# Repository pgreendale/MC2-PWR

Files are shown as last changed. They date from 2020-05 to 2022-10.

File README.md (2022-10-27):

# MC2-PWR compact Eurorack Power Supply
85TE Modular Case - Powersupply

# Introduction 
This Project is a quick - and Dirty Powersupply, which I designed for my modular Eurorack Case. It is relatvely cheap to bild (<60€ for parts). 
To keep tings simple, it has a singlelayer design, which can be easily etched at home (i prefer photolithographic etching, big planes could be difficult to be done with toner transfer). 

# Features 
* +- 12V dual Power supply based on Linear regulators 
* common Gate/CV rail can be divided to use two groups with common Gate/CV
* two 1.5A Fuses to protect against overcurrent 
* screwhole with GND connection for shielding backplates if necessary 

# Parts 
* parts are ordered from Reichelt, a BOM is included in files. 

# Disclaimer 
This project was designed for experienced build. Especially the installation the transformer requires educated building of line powered electronics. To keep things safe, I recommend extra fusing the transformer against overheating and overcurrent on the primary side. Building and operating is done on your own risk! 

Please check the supply under load (take i.E. 10W 12V Lightbulbs from cars etc. one from gnd to +12V and one from gnd to -12V)  first before connecting any Eurorack modules to it. 

# Else 
License GPL v.3
If you like the design or feel the need to make it better, feel free to contact me.

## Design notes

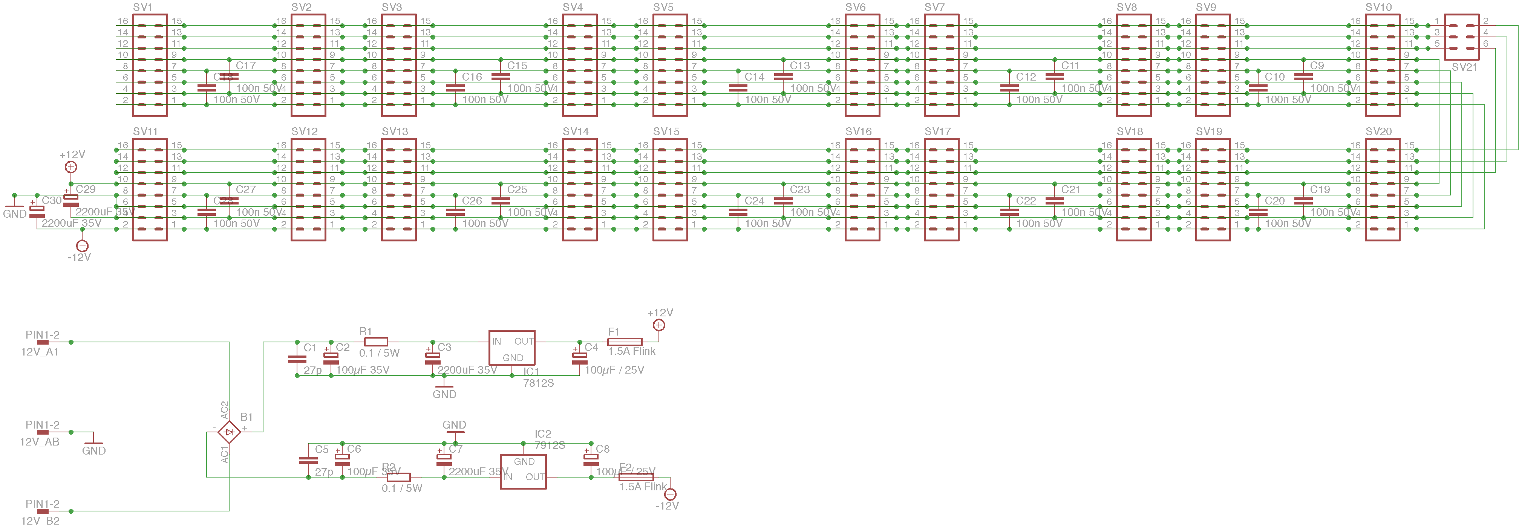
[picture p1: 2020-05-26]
Schematics/Powersupply V 1.10 Schaltplan.png

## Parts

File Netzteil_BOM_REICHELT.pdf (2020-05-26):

## - Netzteil BOM (Reichelt) :

Part | Link | Partnumber (Reichelt) | Rastermaß (mm)
C13 Kaltgeräte male, Einbau | | KES 1 S
Sicherungshalter 5x20 Fronteinbau | | PL126001 | 5x20
Ringkerntrafo 50VA 2x12V, > 1.5A | | RKT 5012
Befestigungsmaterial Ringkern | | mitgeliefert
Flachstecker | | RND 465-00013 | 2,8x0,8
Flachsteckhülse | | RND 465-00056 | 2,8 x 0,8 mm
Graetzbrücke | | KBP 294G TSC
Keramik, 27p | | Kerko 27p | 5
100µF, 35V | | RAD FR 100/35 | 2,5mm
2200µF, 25V | | RAD 2.200/35 | 7,5 mm
0.1Ohm, 0.5W | | ARC ACS5S R 10 K | 13mm = 15mm RM
100uF 25V Low ESR | | FM-A 100U 25 | 2,5 mm
2200uF 25V | | RAD 2.200/35 | 7,5 mm
100nF | | Z5U-2,5 100N | 2,5mm
2k2 Widerstand 0207 | | Metall 2,20K | 7,5mm / 2,5mm
Wannenstecker Male, 8x2, 2.5mm | | WSL 16G | 2,54mm
Crimpstecker, Female, 8x2, 2.5mm | | PFL 16 | 2,54mm
Flachband 16Pol | | AWG 28-16G 3M
Kühlkörper < 3.7*C/W | | V PR127/94-M3
Kühlkörperclip 2,5mm | | MC 725 | 9,1mm
Sicherungshalter 5x20mm print | | PL 112000 | 22,5mm
Sicherungen 1.5A Flink | | FLINK 1.6A

•

# Netzteil

Sonntag, 25. November 2018 19:02

Amount | Cost / Piece (incl. MwSt) € | Cost sum €
1 | 0,86 | 0,86
1 | 0,45 | 0,45
1 | 16,80 | 16,80
6 | 4,59 (á 100) | 4,59
6 | 3,90 (á 100) | 3,90
1 | 0,31 | 0,31
2 | 0,05 | 0,10
2 | 0,23 | 0,46
2 | 0,28 | 0,56
2 | 0,48 | 0,96
2 | 0,14 | 0,28
2 | 0,28 | 0,56
20 | 0,04 | 0,80
2 | 0,082 | 0,164
20 | 0,130 | 2,60
40 | 0,175 | 7,00
10 [m] | 2,10 | 6,30
1 | 2,30 | 2,30
2 | 0,29 | 0,58
2 | 0,190 | 0,38
2 | 0,30 | 0,60

Platinenmaterial | FPE 160x100 | 160x100mm
Befestigungsmaterial

1 | 2,70 | 2,70
| ??
| SUMME | 53,254

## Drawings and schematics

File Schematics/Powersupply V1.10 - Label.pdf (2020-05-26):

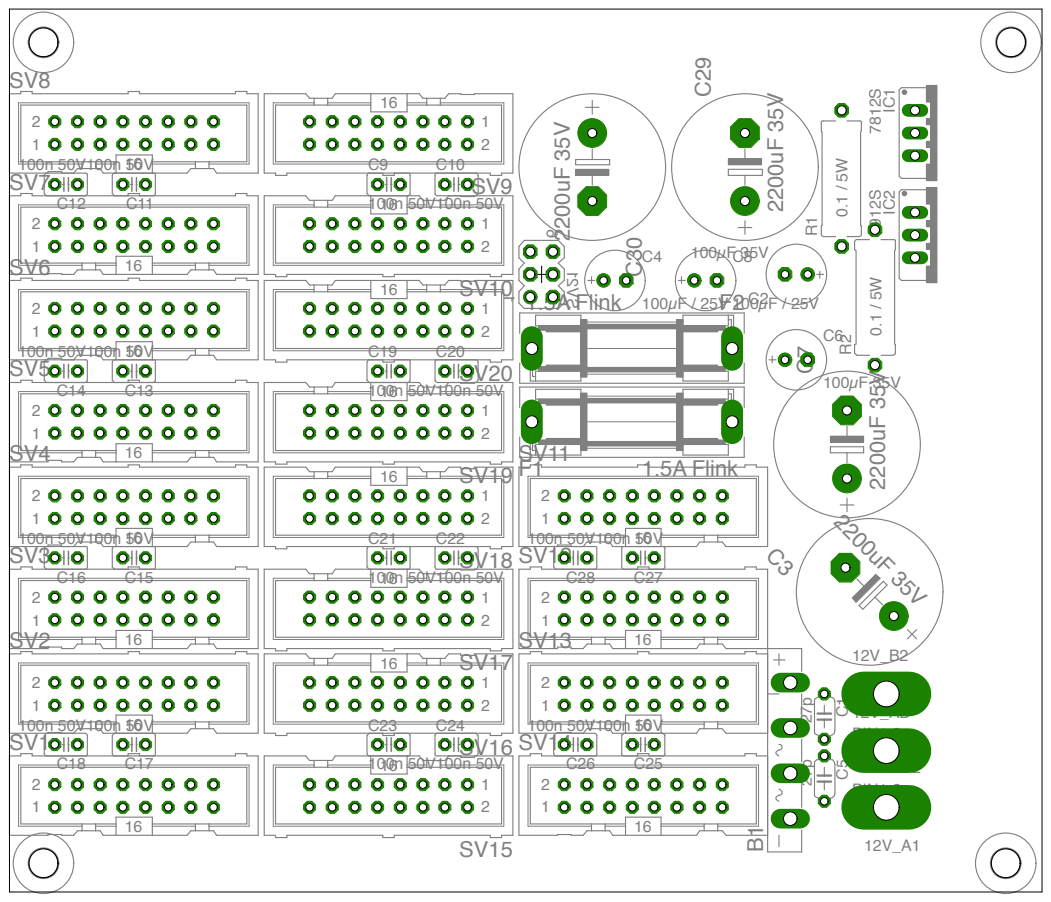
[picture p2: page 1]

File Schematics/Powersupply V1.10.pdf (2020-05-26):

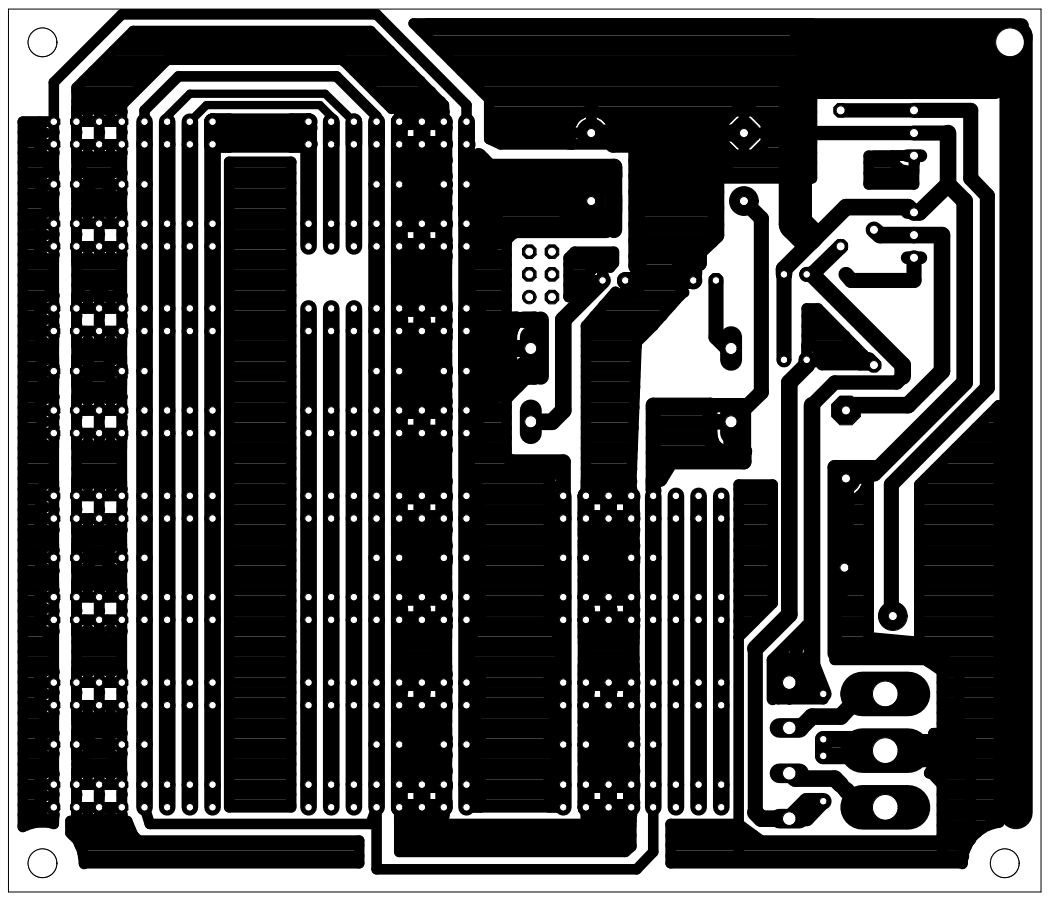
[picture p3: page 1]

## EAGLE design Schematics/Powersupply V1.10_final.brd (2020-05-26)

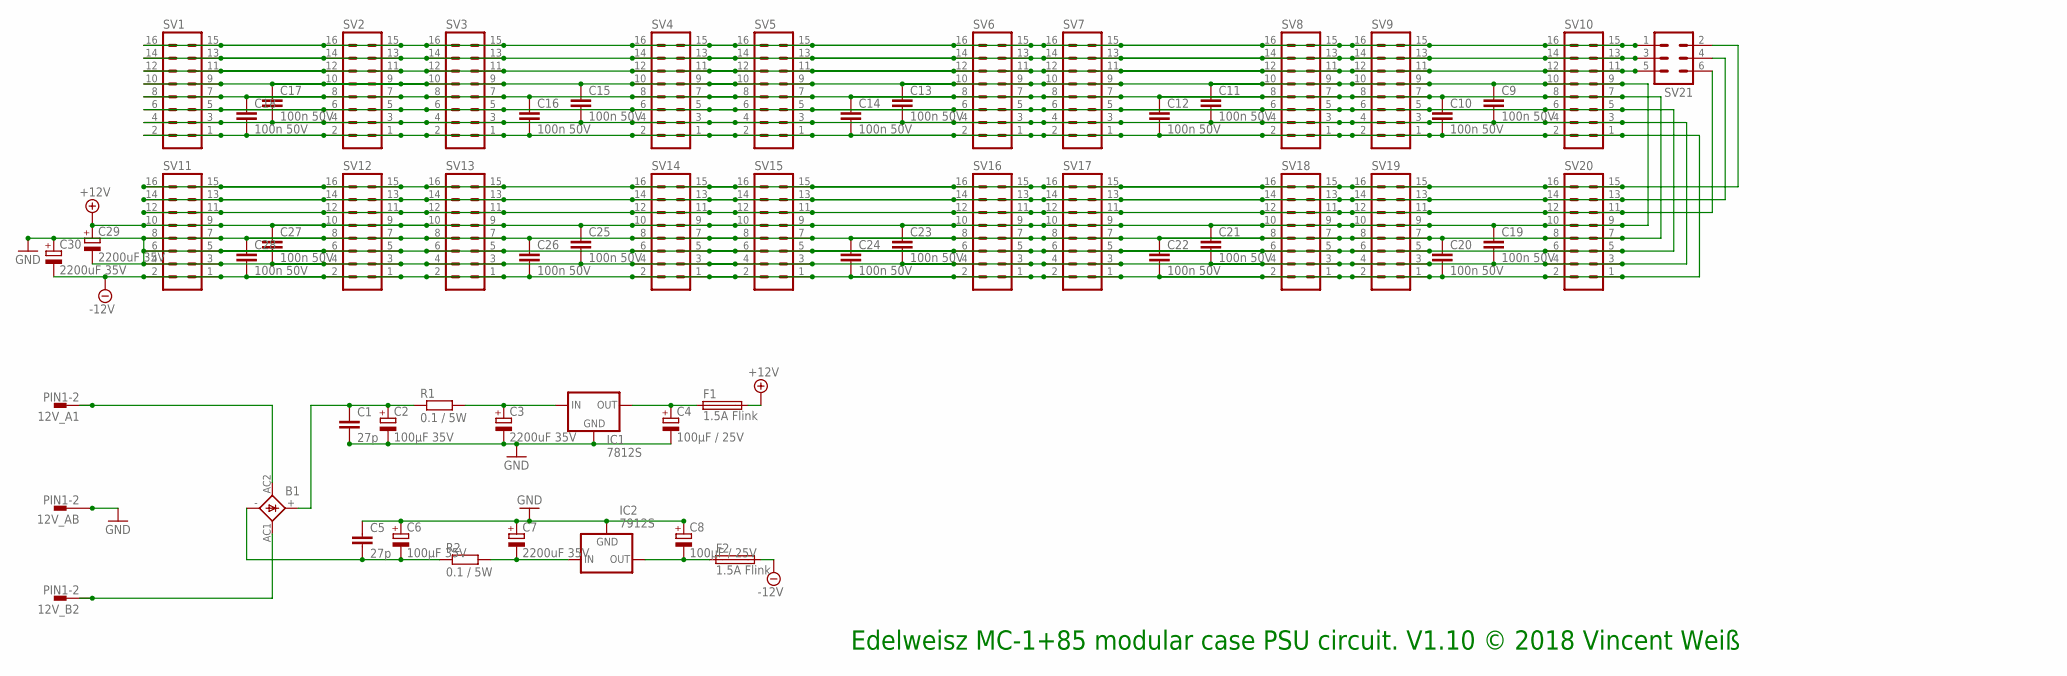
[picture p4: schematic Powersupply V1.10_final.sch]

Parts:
12V_A1, 12V_AB, 12V_B2: PIN1-2; 62221
B1: GBU4; GBU4S
C1, C5: 27p; C050-024X044
C2, C6: 100µF 35V; E2,5-7
C3, C7, C29, C30: 2200uF 35V; E7,5-16
C4, C8: 100µF / 25V; E2,5-7
C9, C10, C11, C12, C13, C14, C15, C16, C17, C18, C19, C20, C21, C22, C23, C24, C25, C26, C27, C28: 100n 50V; C025-025X050
F1, F2: 1.5A Flink; SH22,5
IC1: 7812S; 78XXS
IC2: 7912S; 79XXS
R1, R2: 0.1 / 5W; P0613/15
SV1, SV2, SV3, SV4, SV5, SV6, SV7, SV8, SV9, SV10, SV11, SV12, SV13, SV14, SV15, SV16, SV17, SV18, SV19, SV20: ML16
SV21: MA03-2

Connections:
+12V: C9.1, C11.1, C13.1, C15.1, C17.1, C19.1, C21.1, C23.1, C25.1, C27.1, C29.+, F1.2, SV1.9, SV1.10, SV2.9, SV2.10, SV3.9, SV3.10, SV4.9, SV4.10, SV5.9, SV5.10, SV6.9, SV6.10, SV7.9, SV7.10, SV8.9, SV8.10, SV9.9, SV9.10, SV10.9, SV10.10, SV11.9, SV11.10, SV12.9, SV12.10, SV13.9, SV13.10, SV14.9, SV14.10, SV15.9, SV15.10, SV16.9, SV16.10, SV17.9, SV17.10, SV18.9, SV18.10, SV19.9, SV19.10, SV20.9, SV20.10
-12V: C10.2, C12.2, C14.2, C16.2, C18.2, C20.2, C22.2, C24.2, C26.2, C28.2, C30.-, F2.2, SV1.1, SV1.2, SV2.1, SV2.2, SV3.1, SV3.2, SV4.1, SV4.2, SV5.1, SV5.2, SV6.1, SV6.2, SV7.1, SV7.2, SV8.1, SV8.2, SV9.1, SV9.2, SV10.1, SV10.2, SV11.1, SV11.2, SV12.1, SV12.2, SV13.1, SV13.2, SV14.1, SV14.2, SV15.1, SV15.2, SV16.1, SV16.2, SV17.1, SV17.2, SV18.1, SV18.2, SV19.1, SV19.2, SV20.1, SV20.2
GND: 12V_AB.1, C1.2, C2.-, C3.-, C4.-, C5.1, C6.+, C7.+, C8.+, C9.2, C10.1, C11.2, C12.1, C13.2, C14.1, C15.2, C16.1, C17.2, C18.1, C19.2, C20.1, C21.2, C22.1, C23.2, C24.1, C25.2, C26.1, C27.2, C28.1, C29.-, C30.+, IC1.GND, IC2.GND, SV1.3, SV1.4, SV1.5, SV1.6, SV1.7, SV1.8, SV2.3, SV2.4, SV2.5, SV2.6, SV2.7, SV2.8, SV3.3, SV3.4, SV3.5, SV3.6, SV3.7, SV3.8, SV4.3, SV4.4, SV4.5, SV4.6, SV4.7, SV4.8, SV5.3, SV5.4, SV5.5, SV5.6, SV5.7, SV5.8, SV6.3, SV6.4, SV6.5, SV6.6, SV6.7, SV6.8, SV7.3, SV7.4, SV7.5, SV7.6, SV7.7, SV7.8, SV8.3, SV8.4, SV8.5, SV8.6, SV8.7, SV8.8, SV9.3, SV9.4, SV9.5, SV9.6, SV9.7, SV9.8, SV10.3, SV10.4, SV10.5, SV10.6, SV10.7, SV10.8, SV11.3, SV11.4, SV11.5, SV11.6, SV11.7, SV11.8, SV12.3, SV12.4, SV12.5, SV12.6, SV12.7, SV12.8, SV13.3, SV13.4, SV13.5, SV13.6, SV13.7, SV13.8, SV14.3, SV14.4, SV14.5, SV14.6, SV14.7, SV14.8, SV15.3, SV15.4, SV15.5, SV15.6, SV15.7, SV15.8, SV16.3, SV16.4, SV16.5, SV16.6, SV16.7, SV16.8, SV17.3, SV17.4, SV17.5, SV17.6, SV17.7, SV17.8, SV18.3, SV18.4, SV18.5, SV18.6, SV18.7, SV18.8, SV19.3, SV19.4, SV19.5, SV19.6, SV19.7, SV19.8, SV20.3, SV20.4, SV20.5, SV20.6, SV20.7, SV20.8
unnamed: B1.-, C5.2, C6.-, R2.1
unnamed: 12V_A1.1, B1.AC2 (AC1)
unnamed: 12V_B2.1, B1.AC1 (AC2)
unnamed: B1.+, C1.1, C2.+, R1.1
unnamed: C3.+, IC1.IN, R1.2
unnamed: C7.-, IC2.IN, R2.2
unnamed: C4.+, F1.1, IC1.OUT
unnamed: C8.-, F2.1, IC2.OUT
unnamed: SV1.15, SV1.16, SV2.15, SV2.16, SV3.15, SV3.16, SV4.15, SV4.16, SV5.15, SV5.16, SV6.15, SV6.16, SV7.15, SV7.16, SV8.15, SV8.16, SV9.15, SV9.16, SV10.15, SV10.16, SV21.1
unnamed: SV1.13, SV1.14, SV2.13, SV2.14, SV3.13, SV3.14, SV4.13, SV4.14, SV5.13, SV5.14, SV6.13, SV6.14, SV7.13, SV7.14, SV8.13, SV8.14, SV9.13, SV9.14, SV10.13, SV10.14, SV21.3
unnamed: SV1.11, SV1.12, SV2.11, SV2.12, SV3.11, SV3.12, SV4.11, SV4.12, SV5.11, SV5.12, SV6.11, SV6.12, SV7.11, SV7.12, SV8.11, SV8.12, SV9.11, SV9.12, SV10.11, SV10.12, SV21.5
unnamed: SV11.11, SV11.12, SV12.11, SV12.12, SV13.11, SV13.12, SV14.11, SV14.12, SV15.11, SV15.12, SV16.11, SV16.12, SV17.11, SV17.12, SV18.11, SV18.12, SV19.11, SV19.12, SV20.11, SV20.12, SV21.6
unnamed: SV11.13, SV11.14, SV12.13, SV12.14, SV13.13, SV13.14, SV14.13, SV14.14, SV15.13, SV15.14, SV16.13, SV16.14, SV17.13, SV17.14, SV18.13, SV18.14, SV19.13, SV19.14, SV20.13, SV20.14, SV21.4
unnamed: SV11.15, SV11.16, SV12.15, SV12.16, SV13.15, SV13.16, SV14.15, SV14.16, SV15.15, SV15.16, SV16.15, SV16.16, SV17.15, SV17.16, SV18.15, SV18.16, SV19.15, SV19.16, SV20.15, SV20.16, SV21.2

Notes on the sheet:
Edelweisz MC-1+85 modular case PSU circuit. V1.10 © 2018 Vincent Weiß

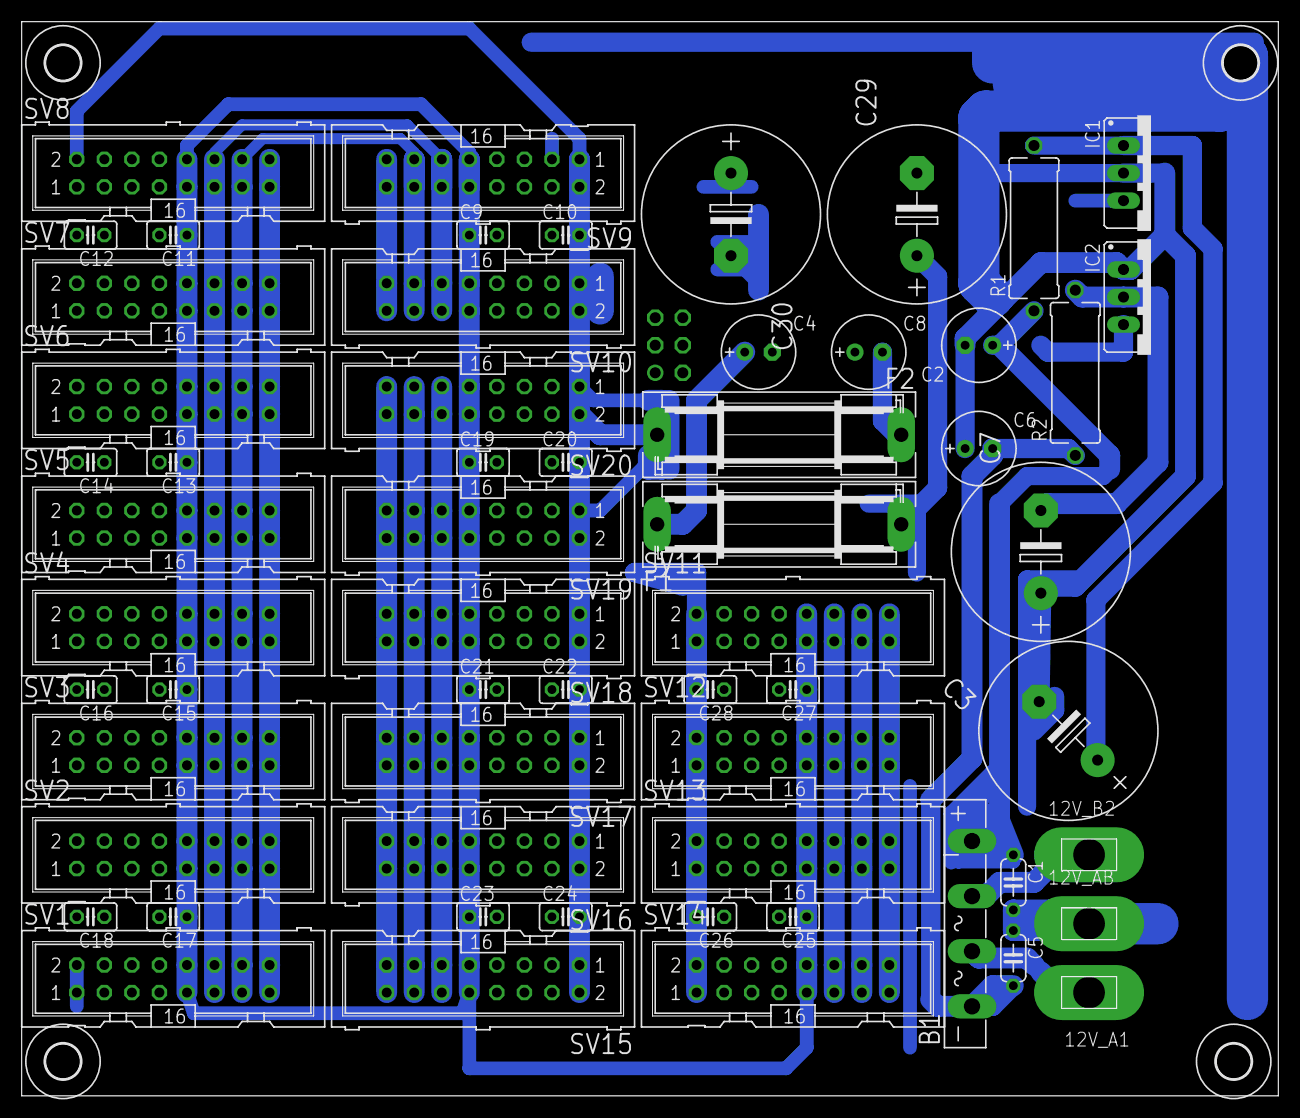
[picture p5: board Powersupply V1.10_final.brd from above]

Board: 2 copper layers, 115.9 x 99.0 mm, 65 parts (1 on the bottom side), 17 nets.

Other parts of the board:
U$1, U$2, U$3, U$4: 3,2
